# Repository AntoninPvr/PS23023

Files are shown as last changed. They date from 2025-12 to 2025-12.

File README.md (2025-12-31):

# PS23023 Linear Power Supply 

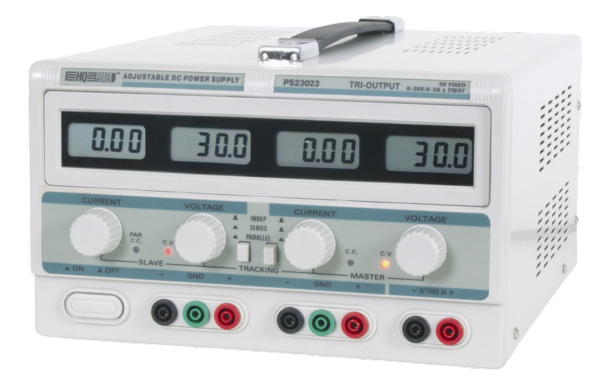
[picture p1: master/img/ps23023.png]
PS23023 Power Supply


I did not find any Kicad design files for the PS23023 from Velleman online, so I created my own from the manufacturer's manual. The design of this power supply seems to be fairly common, their are many clones of it available. 

Manufacturer's manual: [Velleman_PS23023_manual.pdf](B5lJAFJ02yPxKAnPlHxN3OI$bLy67#^%swSE4Qk@sm$*9vJTr9yQ9*vxm1!SRTwx)

**I haven't changed anything from the original design**, It's just a Kicad version of it. It's intended as a reference design to modify my power supply for my own needs.

## Schematic

Board schematics are split into multiple projects:

### Master board

Ref: AQF7.820.7120

Master board: [master/README.md](master/README.md)

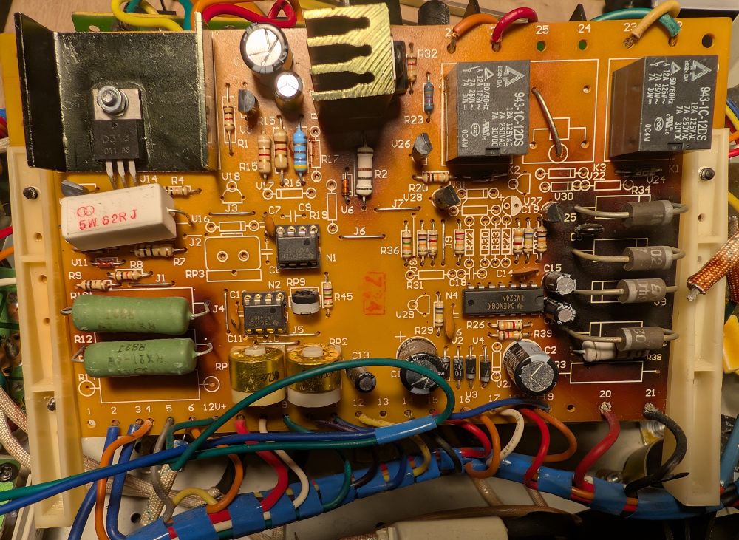
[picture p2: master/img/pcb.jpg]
front


### Charge pump board

Ref: AQF7.820.7173

Charge pump board: [charge_pump/README.md](charge_pump/README.md)

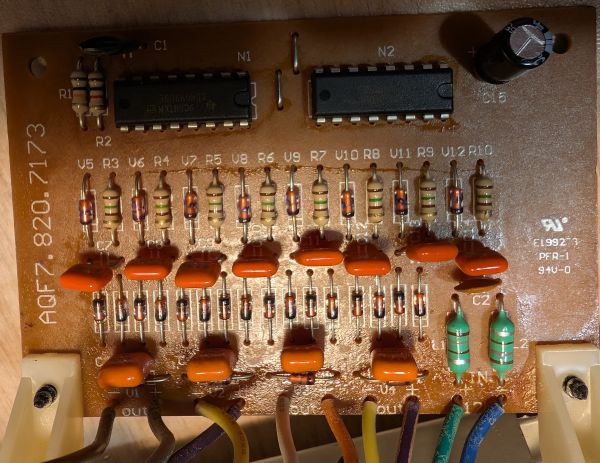
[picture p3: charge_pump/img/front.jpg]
charge_pump


### 5V 3A supply

Ref: AQF7.820.775

5V 3A supply: [5v_supply/README.md](5v_supply/README.md)

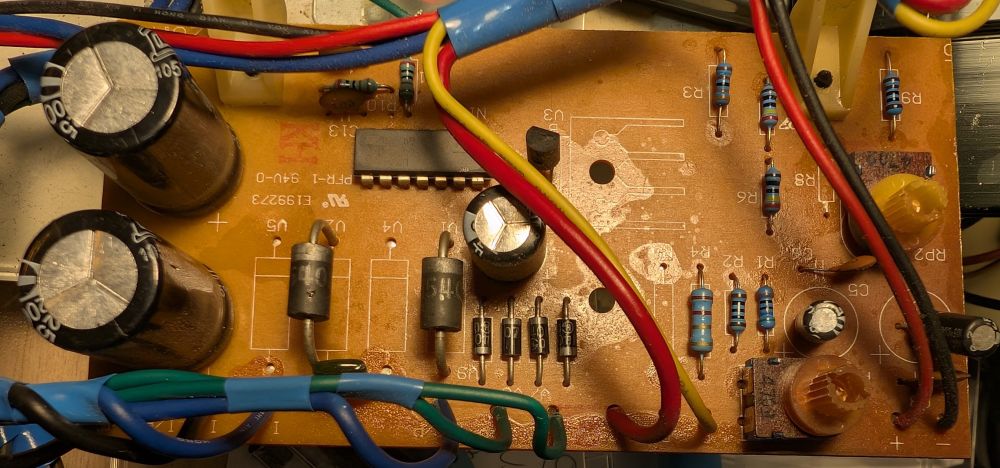
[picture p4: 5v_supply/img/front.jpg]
5v_supply


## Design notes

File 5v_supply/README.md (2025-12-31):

# 5V 3A supply

(Ref: AQF7.820.775)

**I haven't changed anything from the original design**, It's just a Kicad version of it. It's intended as a reference design to modify my power supply for my own needs.

## Schematic

This supply is based on the LM723 voltage regulator IC with a single 2n3055 ballast.

It uses a middle tap transformer and an auxiliary winding to power the LM723. The general design is weird, but it's can be related to my own PS23023 power supply, as the serigraphy on the PCB for wires is a bit confusing.

Full schematic: [5v_supply.pdf](pdf/5v_supply.pdf)

5v_supply

## Pictures

### Front

front

### Back

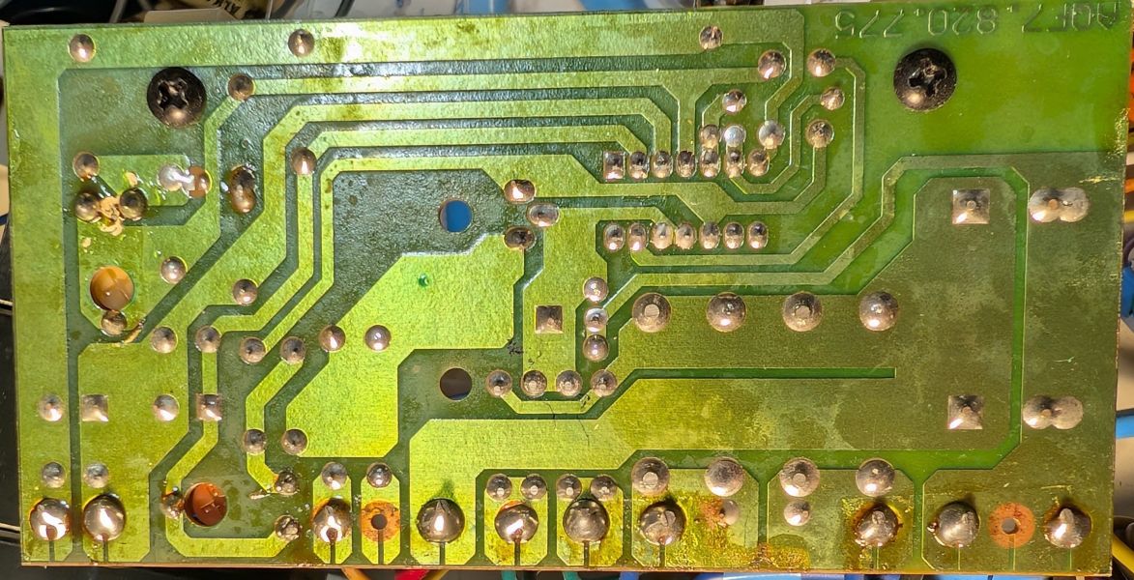
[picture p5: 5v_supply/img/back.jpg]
back


### Pins serigraphy

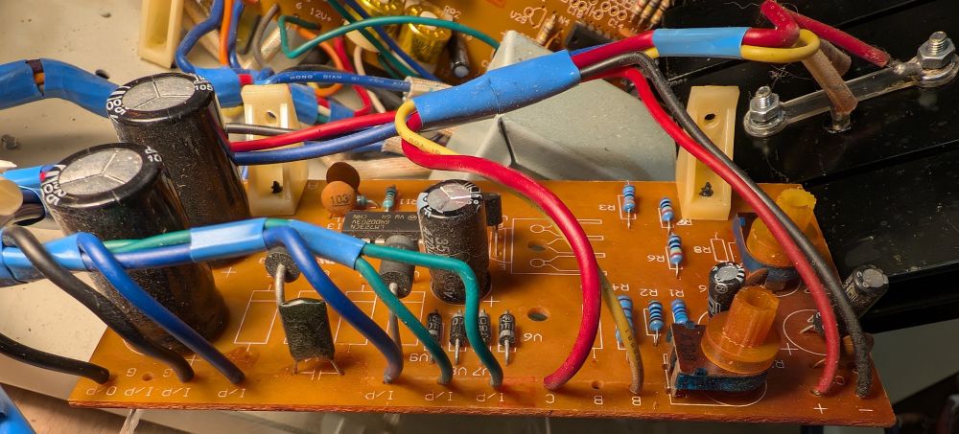
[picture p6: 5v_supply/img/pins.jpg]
pins


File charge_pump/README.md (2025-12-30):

# Charge pump circuit 4x 9V

(Ref: AQF7.820.7173)

**I haven't changed anything from the original design**, It's just a Kicad version of it. It's intended as a reference design to modify my power supply for my own needs.

## Schematic

This is the charge pump schematic used to supply all lcd voltmeters/ammeter modules with 4 "isolated 9V supplies".

Switching circuit use only CD4049UBE and the frequency is set by R1 and C1. You can adjust them to change the frequency if needed. I measured around 40kHz with the given values.

Full schematic: [charge_pump.pdf](pdf/charge_pump.pdf)

charge_pump

## Pictures

### Front

front

### Back

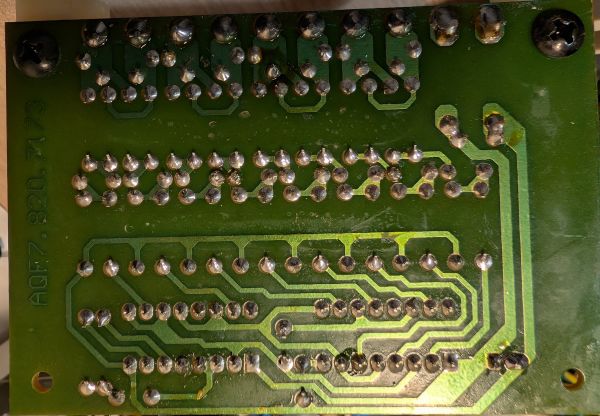
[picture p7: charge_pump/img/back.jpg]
back


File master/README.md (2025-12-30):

# Master Board 0-30V 0-3A

(Ref: AQF7.820.7120)

**I haven't changed anything from the original design**, It's just a Kicad version of it. It's intended as a reference design to modify my power supply for my own needs.

## Schematic

Master schematic, the slave is identical, except the control potentiometers are different because they are routed through Serial/Parallel/Independent switches.

### Root

Full schematic: [master.pdf](pdf/master.pdf)

Root

### Auxilliary Power Supply

Aux

### Tap Switching

Tap Switching

### Current Loop

Current Loop
### Voltage Loop

Voltage Loop

## Transformer

All voltages are measured without load.

```
Primary       Secondary
230v ---|   |--- 18v   (Aux winding)
        |   |
        |   |--- 0v
        |   |
        |   |--- -18v
        |
        |   |--- 39v    tap 1 (green)
        |   |
        |   |--- 31v     tap 2 (yellow)
        |   |
        |   |--- 16v   tap 3 (orange)
        |   |
0v   ---|   |--- 0v   tap 4 (red)
```

## Tap Switching

Here is the switching diagram of the transformer:

| Taps | Color | Voltage |
|---|---|---|
| 2-4  | Yellow-Orange | 14.6V |
| 1-4  | Green-Orange  | 22.7V |
| 2-3  | Yellow-Red | 30.9V |
| 1-3  | Green-Red | 39.0V |

We can see that voltages are not equally spaced.

## Tuning

The power supply can be tuned by adjusting the following components:

- **RP2**: Adjusts the maximum output voltage range.

- **RP1**: Adjusts the maximum output current range.

- **RP9**: Adjusts the offset current, to ensure 0A at minimum setting.

## Pictures

### Master PCB

PCB

### Transformer

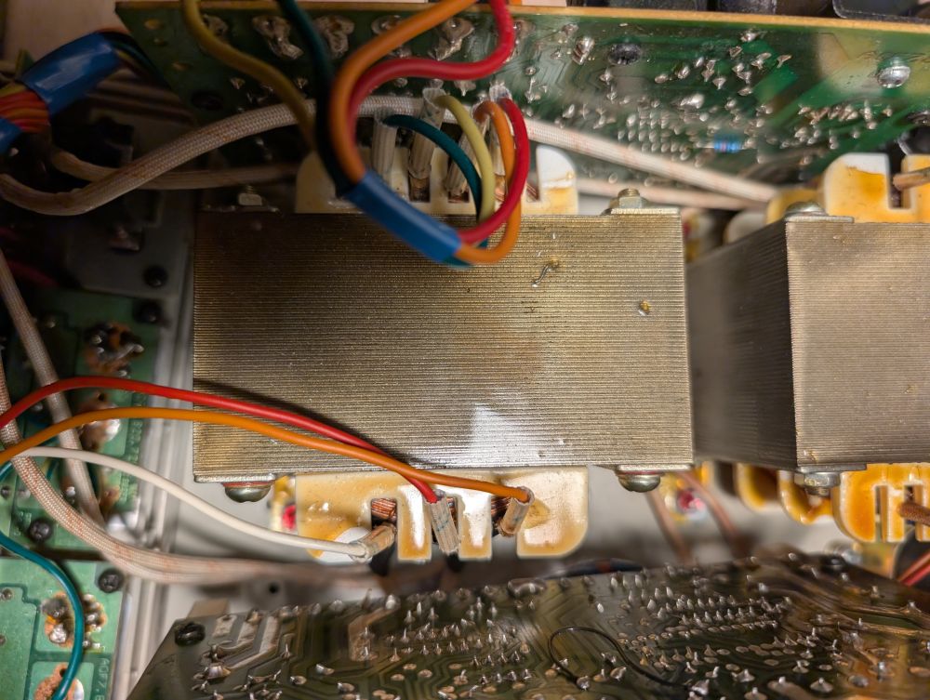
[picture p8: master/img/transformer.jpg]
Transformer


### Ballast Transistor

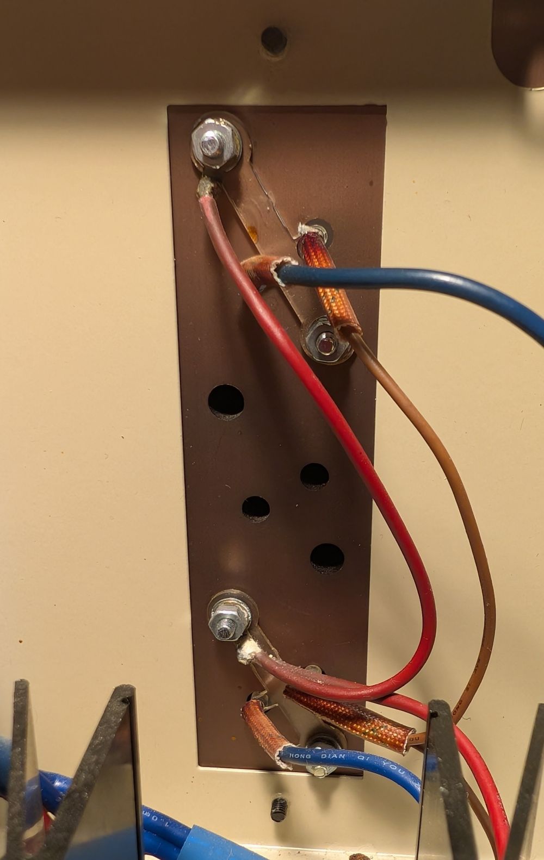
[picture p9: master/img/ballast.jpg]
Ballast Transistor


## Notes

Some components may vary depending on the version of the power supply. For example, in my supply `U18`, `U17`, `R17` and `R19` are not populated. Also it shows some unpopulated components for an additional relay that is not present in my version.

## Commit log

2025-12-30 Change folder structure
    [auxiliary.kicad_sch, current_control.kicad_sch, master.kicad_pcb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]
2025-12-30 Added charge pump circuit
    [charge_pump.kicad_pcb, charge_pump.kicad_sch]
2025-12-30 Added pictures for charge pump
    [auxiliary.kicad_sch, charge_pump.kicad_sch, current_control.kicad_sch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]
2025-12-31 Added 5V 3A supply
    [5v_supply.kicad_pcb, 5v_supply.kicad_sch]
